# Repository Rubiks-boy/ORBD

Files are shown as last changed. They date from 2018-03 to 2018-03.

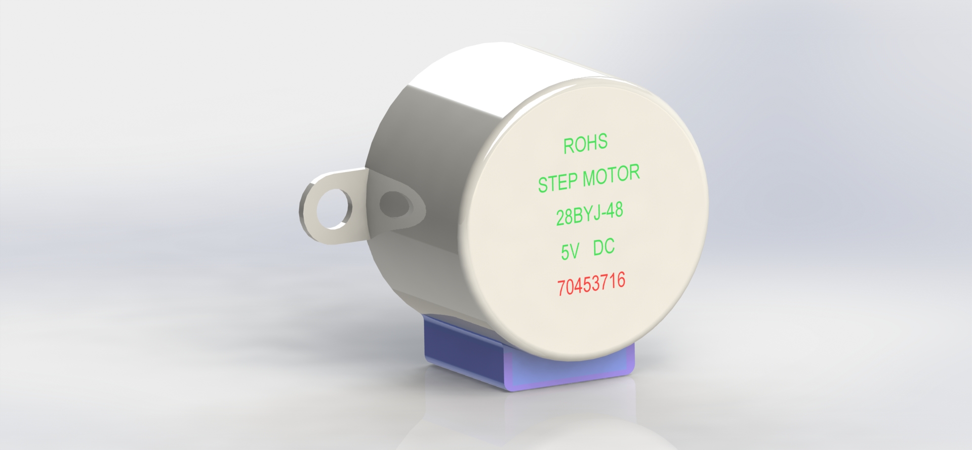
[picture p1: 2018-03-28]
IPT Inventor Files/Stepper Motor/5v DC step motor (back).JPG

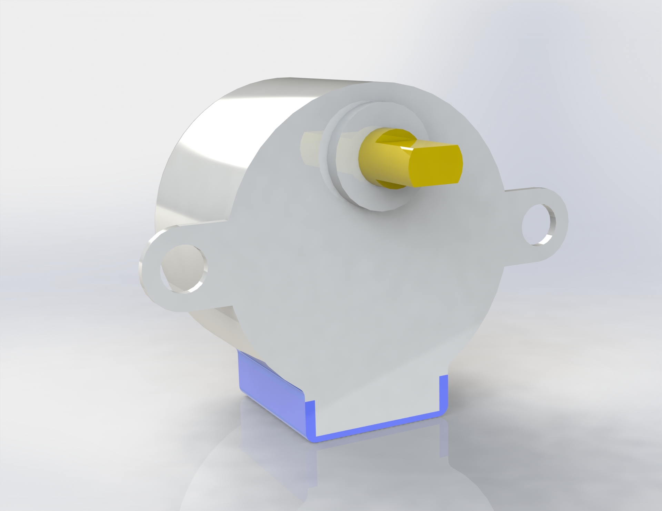
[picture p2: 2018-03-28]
IPT Inventor Files/Stepper Motor/5V Step motor.JPG

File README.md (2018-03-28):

# ORBD
Open Refreshable Braille Display - Science Fair Project by Adam Walker &amp; Russell Ro

This project uses motors in order to spin wheels that display a variety of braille characters quickly at less than 1% of the cost of present braille displays on the market.

Abstract:

285 million people are estimated to be visually impaired worldwide. Many of these individuals do not have access to blind-assistive technology primarily due to cost and accessibility. One such device, the refreshable braille display, converts digital text to a tactile readout providing a valuable tool in reading and writing applications. However, prices range from $3,500 to $15,000 making it difficult for many low-income visually impaired individuals to buy a device, especially since non-institutionalized persons aged 21-64 years with a visual disability have a median annual household income of $39,700 and about 29% of them live below the poverty line. Since many refreshable braille displays are prohibitively expensive, previous approaches have attempted to lower its cost by restricting the number of characters displayed, but this arose the new problem of higher translation error rates. In order to make refreshable braille displays more effective for a greater number of visually impaired individuals, our open-source device, ORBD, will provide a cheaper alternative to existing braille displays that does not sacrifice on readability, including the number of characters. ORBD is controlled by an Arduino microcontroller that takes digital input through a computer and translates those characters to a stepper motor position. An octagonal tactile surface connected to the motor via gear train displays the characters accordingly. Depending on user preference, more characters may be added by attaching extra gears and stepper motors. By accounting for accessibility through it being open-source, users have access to assembling their own refreshable braille display with parts that amount to a fraction of other devices’ prices.

This project competed at the Beal Bank USA Southern Nevada Regional Science & Engineering Fair at the University of Nevada, Las Vegas on March 14, 2018.

Adam Walker - adamwalker567123@gmail.com (Programming)
Russell Ro - pr.russell.ro@gmail.com (3D Modeling)

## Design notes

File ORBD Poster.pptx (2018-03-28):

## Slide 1

- Russell Ro, Adam Walker

- Advanced Technologies Academy, Las Vegas NV 89106

- Open Refreshable Braille Display (ORBD)

- Introduction

- 285 million people are estimated to be visually impaired worldwide.
- Non-institutionalized persons aged 21-64 years have median annual household income of $39,700 and about 29% of them live below the poverty line.
- A refreshable braille display converts digital text to a tactile readout providing a valuable tool in reading and writing applications.
- Prices range from $3,500 to $15,000.
- Cheaper alternatives suffered from higher translation error rates due to restricted number of characters.
- Open Refreshable Braille Display
- Arduino microcontroller-based that takes digital input through serial and translates those characters to braille readout.
- Accessibility: Budget set to approximately $100; will be released as an open-source device.
- Education: Practical in educational settings through use of digital text translation (i.e. textbooks, homework, etc.).
- Character Limitation: Doesn’t sacrifice on readability due to a character additive design.

- Hardware

- Results and Discussion

- The Open Refreshable Braille Display (ORBD) satisfies three objectives:
- Accessibility: Comprised of easily-obtainable hardware that amounts to approximately $70 if built personally or as low as $15 if mass-produced.
- Education: Successfully translates characters typed onto a computer to a stepper motor’s position which outputs braille characters; allows for an instructor to use as real-time educational tool (i.e. teaching braille characters).
- Character Limitation: Utilizes an axle and 3D-printed parts, allowing the user to expand the amount of characters on their device; each additional character costs about $3 (includes stepper motor, driver, and 3D-printed parts).

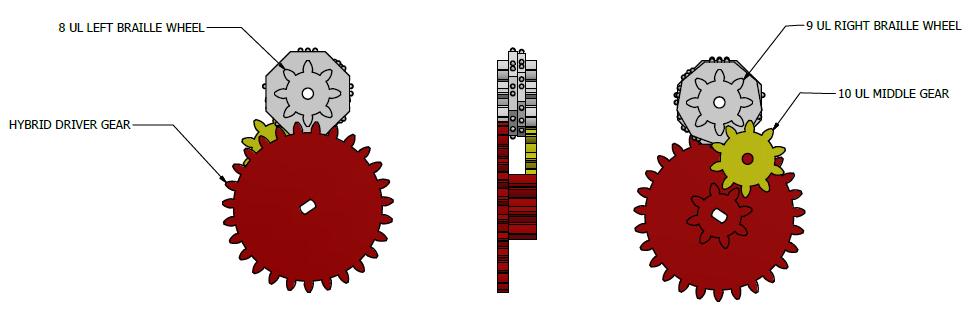
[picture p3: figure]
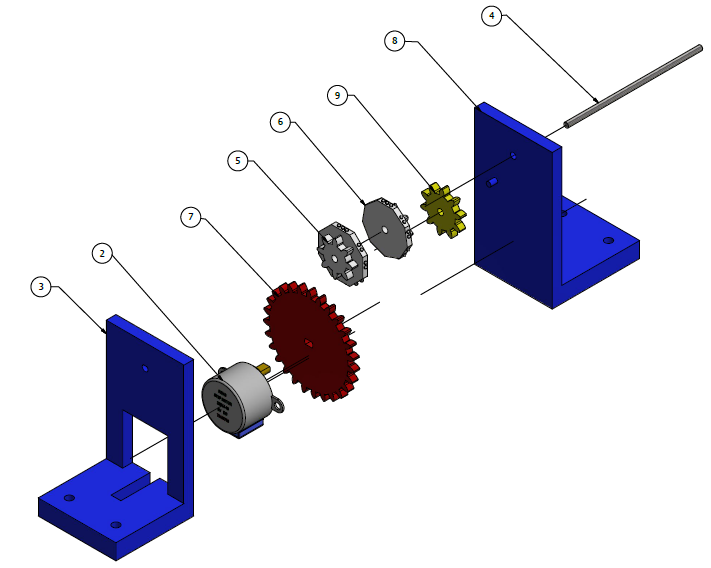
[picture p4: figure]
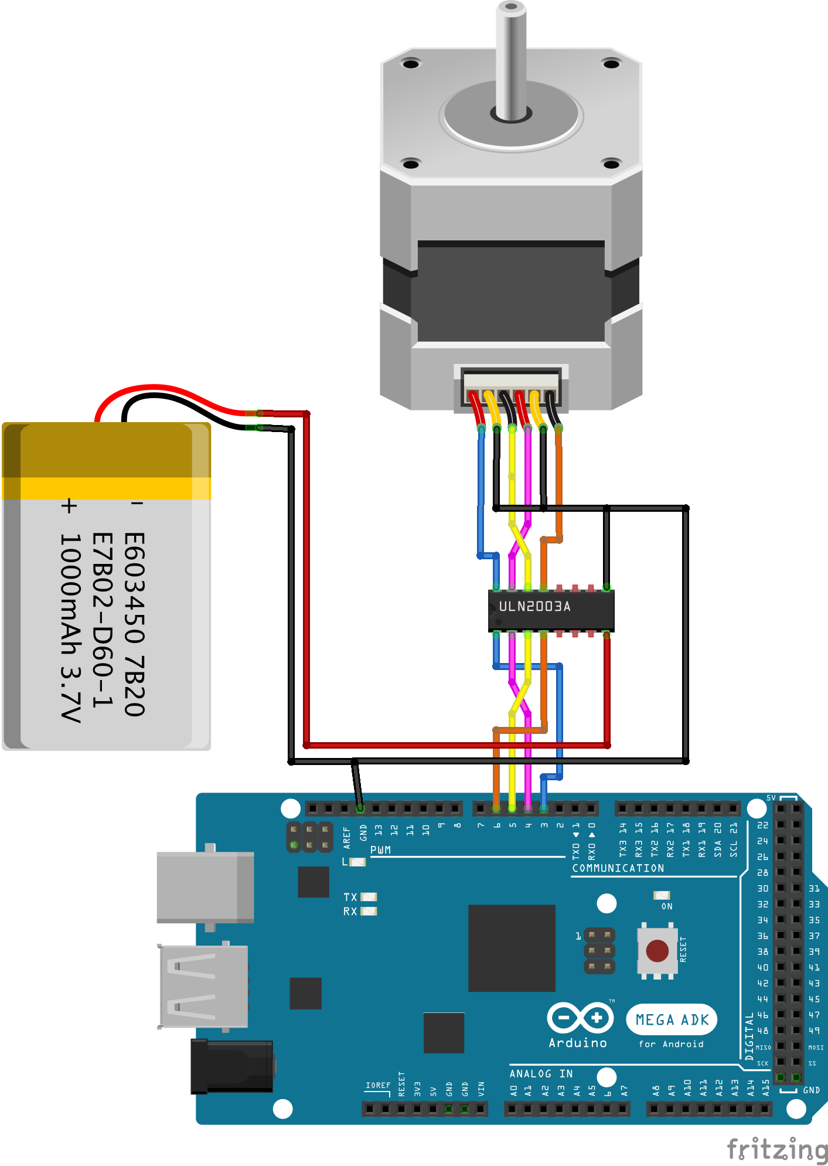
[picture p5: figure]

The ‘Hybrid Driver Gear’ consists of two sets of gear: one with 27 teeth and one with 8 teeth. The 27-tooth gear drives the 8-tooth octagonal left braille wheel, while the 8-tooth gear drives the 8-tooth nonagonal right braille wheel with a 10-tooth middle gear in between.

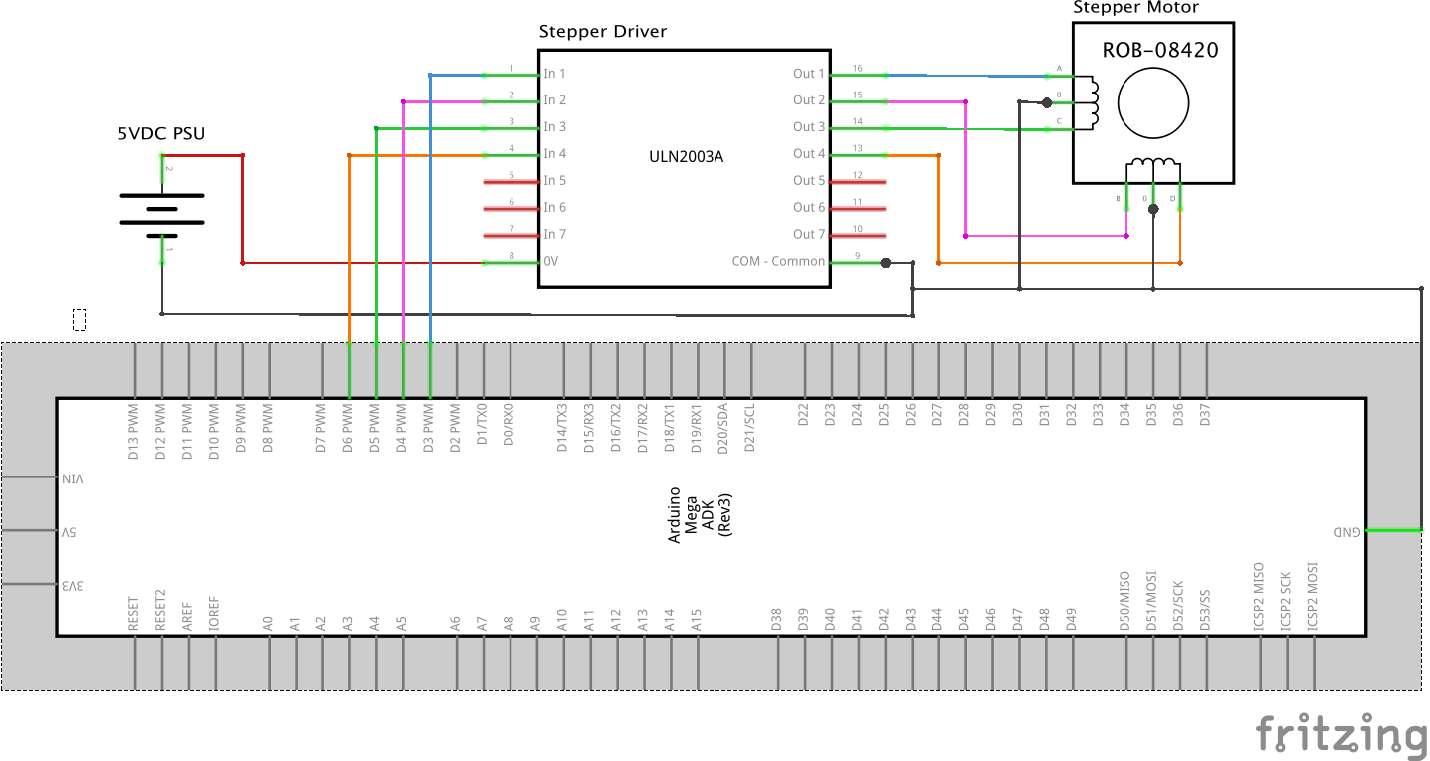
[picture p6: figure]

Gear Ratio Simulations

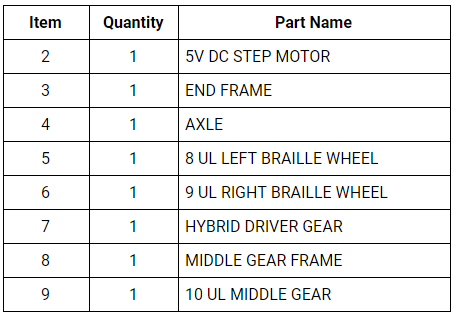
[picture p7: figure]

ORBD is a gear-based stepper motor concept that uses one stepper motor per character. Since this design saves on costs as it uses one motor for the two braille wheels that comprise one character instead of two motors. In order to find the ideal gear ratios, we ran simulations and resulted in using an 8:27 gear ratio that runs octagonal and nonagonal braille wheels per character. The 8:27 was chosen for its reasonable tooth-proportions and lowest average iterations to get from one character to the next (17.5). However, this design resulted in more challenges compared to the simpler, more expensive concepts:
- Extra gears made the device more prone to jams especially given that 3D printed parts aren’t perfect.
- It takes longer to translate digital text to braille output due to the device having less motors.
- Although ORBD has the additive character feature, each character is much bigger than current models’ character making for an inconveniently-sized braille display.
However, the benefits outweigh the drawbacks due to cost. The ORBD stands at an affordable $70 compared to the average price range of $3,500 to $15,000. With open-source access, ORBD has the potential to reach the millions of visually-impaired people who need it most.

Design Concepts

Solenoid-Based Concept: Each “bump” is raised using solenoids arranged in a 2x3 grid.
Pros:
- Characters change near instantaneously
Cons:
- Solenoids are too large & too many I/O pins to expand past a handful of characters.
- Power is required at all times to keep characters.

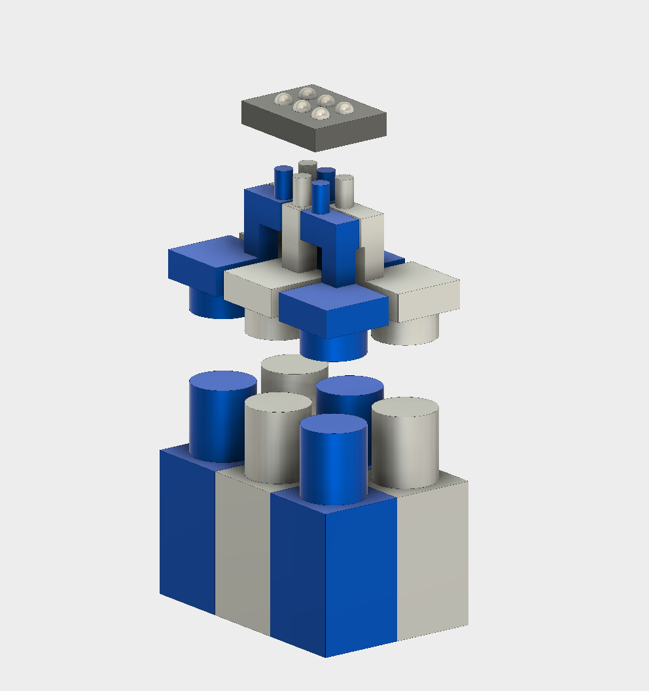
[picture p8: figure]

- To reduce costs and size, the left and right wheels are geared together. As it is necessary for the gears to maintain a flat surface at all times, the gear ratio must be such that all 64 combinations of characters* can be displayed accurately. A computer simulation was used to test the efficiency of various gear ratios.
- Let L and R be the number of positions on the left and right wheels, respectively.
- For every position moved forward on the right wheel, let n be the number of positions the left wheel moves such that 2 ≤ n < L.
- When there are eight positions on each wheel (L = R = 8), there is no n that will display all 64 combinations.
- Thus, we ran simulations that add “nothing” positions that don’t display characters:
- For every left wheel size L such that 8 ≤ L < 25
- For every right wheel size R such that 8 ≤ R < 25
- For every ratio n such that 2 ≤ n < L
- If every single position can be displayed, we log the mean and maximum number of iterations required (one iteration being moving one position forward on the slower wheel) to reach any character.
- The simulation ran forwards only. These numbers can be cut in half by running motors backwards and forwards.
- In addition, the true gear ratio that resulted was calculated and logged
- * Each wheel is responsible for one column of three bumps with 2³=8 permutations. Thus, there are 8²=64 possible characters that can be displayed.

Ave(Iter.) | Max(Iter.) | Slow Size R | Fast Size L | Pos Ratio n | Ave(R Revs) | Max(R Revs) | Ave(L Revs) | Max(L Revs) | Actual Gear Ratio
35 | 70 | 9 | 8 | 3 | 3.89 | 7.78 | 13.13 | 26.25 | 8:27
35 | 70 | 9 | 8 | 5 | 3.89 | 7.78 | 21.88 | 43.75 | 8:45
35 | 70 | 9 | 8 | 7 | 3.89 | 7.78 | 30.63 | 61.25 | 8:63
35 | 70 | 9 | 8 | 9 | 3.89 | 7.78 | 39.38 | 78.75 | 8:81
35 | 70 | 9 | 8 | 11 | 3.89 | 7.78 | 48.13 | 96.25 | 8:99
35 | 70 | 9 | 8 | 13 | 3.89 | 7.78 | 56.88 | 113.75 | 8:117
35 | 70 | 9 | 8 | 15 | 3.89 | 7.78 | 65.63 | 131.25 | 8:135
…
379 | 529 | 24 | 23 | 22 | 15.79 | 22.04 | 362.4 | 506 | 23:528

Travel Times

Based on the simulations, R = 9, L = 8, n = 3, and an 8:27 gear ratio was the most efficient (both in average time and in worst-case scenarios) and yielded the quickest travel times for a single character. As more characters are added, the travel iterations and travel times are logarithmic in shape and approach the values of 35 iterations and 15.575 seconds (@15RPM), respectively, as the number of characters approaches infinity.
In testing the responsiveness of changing characters, there is a negligible delay that averages 4ms, no matter the motor’s speed, as measured by the Arduino. Though the stepper motor’s top speed was approximately 20 RPM, all tests were conducted at 15 RPM to ensure the stepper motor did not lose steps.

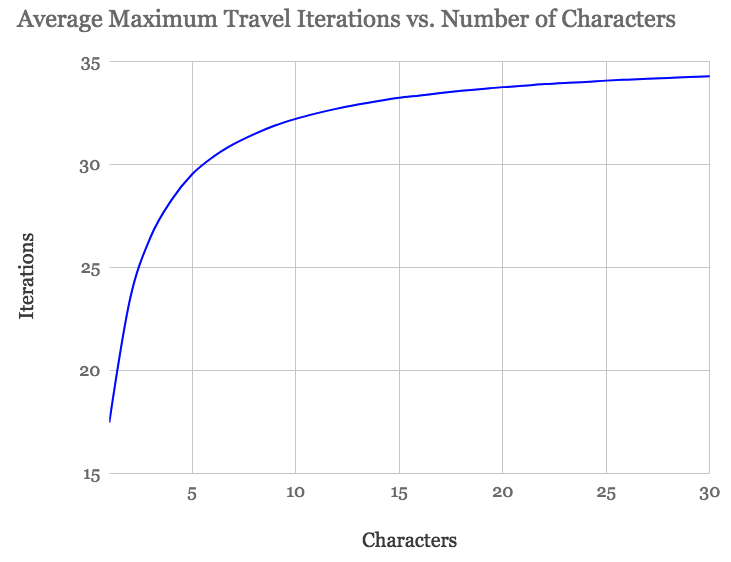
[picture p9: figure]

Derailleur Concept: Similar to a bicycle changing gears, a mechanism allows switching between characters displayed on a single wheel of 8 combinations of bumps.
Pros:
- Two motors required for a theoretically infinite number of characters.
Cons:
- One wheel can be moved at a time.
- The mechanism to switch wheels is complex, causing greater potential for jams.

Gear-Based Stepper Motor Concepts: Wheels of 8 combinations of bumps (1 column of a character) are driven by stepper motors.
V1: One stepper motor per wheel (2 per character)
V2: One stepper motor per character & a 27:8 gear ratio connects the two wheels.
Pros:
- Uses only one motor (V2) or two motors (V1) per wheel.
- In V1, each motor travels at most half of a revolution. In V2, on average, the faster wheel travels 6.56 revolutions and the slower 1.94.
- Allows characters to be placed next to each other as long as there are I/O pins.
- All motors can be driven at the same time.
Cons:
- Requires two stepper motors per character, resulting in greater cost and size. This may require more space between each character.
- Each motor requires a stepper motor driver, and the power supply must be strong enough to drive every motor.
- If the microcontroller loses power or the stepper loses steps, the device loses track of its position.

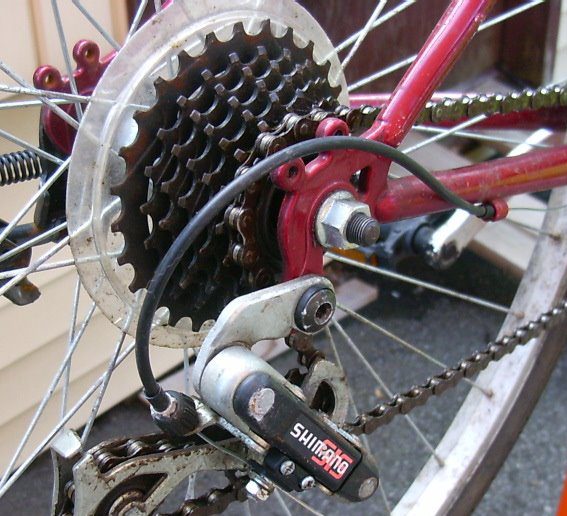
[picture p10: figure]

http://www.howtofixbikes.ca/2006/07/adjusting-your-derailleur.html

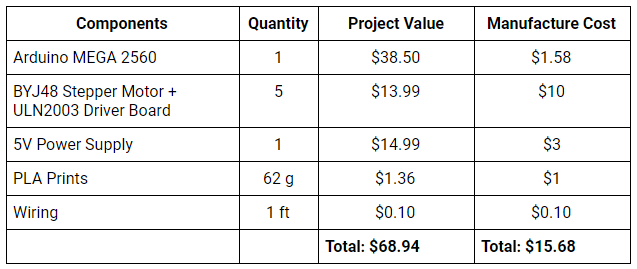
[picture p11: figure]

- Conclusion

- The Open Refreshable Braille Display is able to convert digital text into familiar braille text in a way that does not sacrifice readability. Its form factor is expandable, theoretically allowing for more characters than anything currently on the market. Most importantly, it could be manufactured for as little as one one-thousandth the cost of existing displays, removing any economic barrier. As an open-source alternative, ORBD will be able to revolutionize computer use, including for e-books and e-textbooks, for the visually impaired.

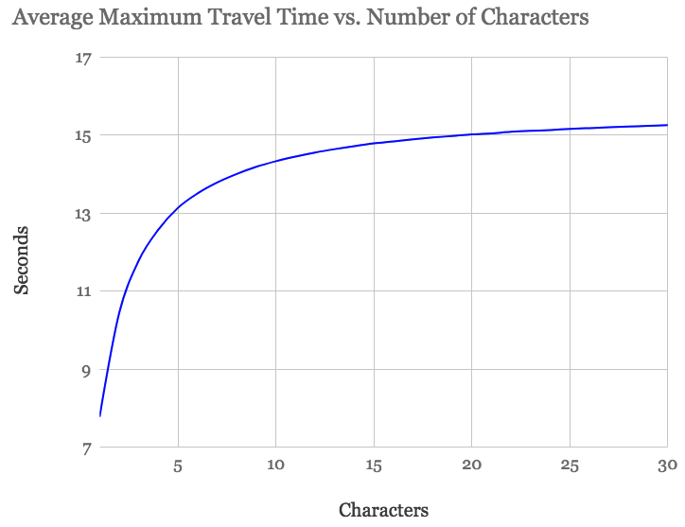
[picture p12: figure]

- References

- Vision impairment and blindness. (2017, October). Retrieved January 21, 2018, from http://www.who.int/mediacentre/factsheets/fs282/en/
- Refreshable Braille Displays. (n.d.). Retrieved January 21, 2018, from http://www.afb.org/prodBrowseCatResults.aspx?CatID=43
- Blindness Statistics. (n.d.). Retrieved January 21, 2018, from https://nfb.org/blindness-statistics
- Russomanno, A., Omodhrain, S., Gillespie, R. B., & Rodger, M. W. (2015). Refreshing Refreshable Braille Displays. IEEE Transactions on Haptics,8(3), 287-297. doi:10.1109/toh.2015.2423492

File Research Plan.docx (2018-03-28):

Open Refreshable Braille Display (ORBD)

Russell Ro, High School Student

Adam Walker, High School Student

Advanced Technologies Academy

1411 Robin Street

Las Vegas, NV 89106

Contact:

pr.russell.ro@gmail.com, 626-828-0560

adamwalker567123@gmail.com, 702-330-2590

Rationale

285 million people are estimated to be visually impaired worldwide [1]. Many of these individuals do not have access to blind-assistive technology primarily due to cost and accessibility. One such device, the refreshable braille display, converts digital text to a tactile readout providing a valuable tool in reading and writing applications. However, prices range from $3,500 to $15,000 [2] making it difficult for many low-income visually impaired individuals to buy a device, especially since non-institutionalized persons aged 21-64 years with a visual disability have a median annual household income of $39,700 and about 29% of them live below the poverty line [3]. Since many refreshable braille displays are prohibitively expensive, previous approaches have attempted to lower its cost by restricting the number of characters displayed, but this arose the new problem of higher translation error rates [4]. In order to make refreshable braille displays more effective for a greater number of visually impaired individuals, our open-source device, ORBD, will provide a cheaper alternative to existing braille displays that does not sacrifice on readability, including the number of characters.

Question

What changes to the refreshable braille display can allow for more affordability and accessibility?

Hypothesis

A new refreshable braille display design will be able to reach more visually impaired individuals without sacrificing its usability.

Engineering Goals

- Draft multiple design possibilities to pursue
- Prototype a new approach to a refreshable display at a feasible price
- Can display computer text input in a standard braille alphabet
- Minimizes cost
- Provides an expandable platform to increase the number of characters
- Make device open-source for public accessibility
- If time permits, receive feedback from the Blind Center of Nevada
- Test the readability of the device
- Donate the prototype to allow for further feedback and research

Expected Outcomes

A printer-based rail design allows for a stepper motor and gear to turn wheels with tactile braille to appropriate characters. Magnets will assist the wheels to stay at their appropriate characters. Since the wheels rest on a central axle and the motor on the rail theoretically has unlimited extendability, more wheels may be added allowing for more characters to be displayed.

Procedures

1. Pre-planning a prototype by making schematics, 3D models, and preliminary plans for development.
2. Assemble the prototype, including using soldering, 3D printers, and other techniques to develop an original design.
3. After each prototype revision, test the following measurements:
  a. Accuracy and readability of characters displayed
    i. Compare output to standard braille alphabet
    ii. Compare height of characters and spacing of characters to standards for height and spacing
    iii. If time permits, allow individuals to provide feedback on the readability of the display
  b. Attributes of the design
    i. Measure the speed of changing characters, including mean, variance, best case, and worst case
    ii. Calculate and log all costs, including electronics and 3D printed components
    iii. Measure size of device and power usage
    iv. Other attributes as applicable
  c. Attributes of the design
    i. Compare ORBD designs, drafts, and prototypes based on criteria in (a) and (b), as applicable
    ii. Compare these attributes with other displays currently on the market, as applicable

Risk and Safety

There will be no risks to any participants or other parts involved in data collection. During assembling, 3D printers and soldering pose a potential heat risk, but by following proper precautions, this risk will remain at a minimum. Low-voltage and low-amperage electronics pose minimal to no risk.

Data Analysis

The device must first prioritize power efficiency as inefficient actuator design may limit the performance of the microcontroller, so power capabilities will be considered in the draft designs. Next, the speed and accuracy will be measured through inputting characters on a computer, translating them to the display, and recording the time it took and the correctness of the characters based on what was inputted in the computer. Lastly, a cost-benefit analysis for the draft designs and prototype will detail its feasibility as compared to other models.

Bibliography

[1] Vision impairment and blindness. (2017, October). Retrieved January 21, 2018, from http://www.who.int/mediacentre/factsheets/fs282/en/
[2] Refreshable Braille Displays. (n.d.). Retrieved January 21, 2018, from http://www.afb.org/prodBrowseCatResults.aspx?CatID=43
[3] Blindness Statistics. (n.d.). Retrieved January 21, 2018, from https://nfb.org/blindness-statistics
[4] Russomanno, A., Omodhrain, S., Gillespie, R. B., & Rodger, M. W. (2015). Refreshing Refreshable Braille Displays. IEEE Transactions on Haptics,8(3), 287-297. doi:10.1109/toh.2015.2423492

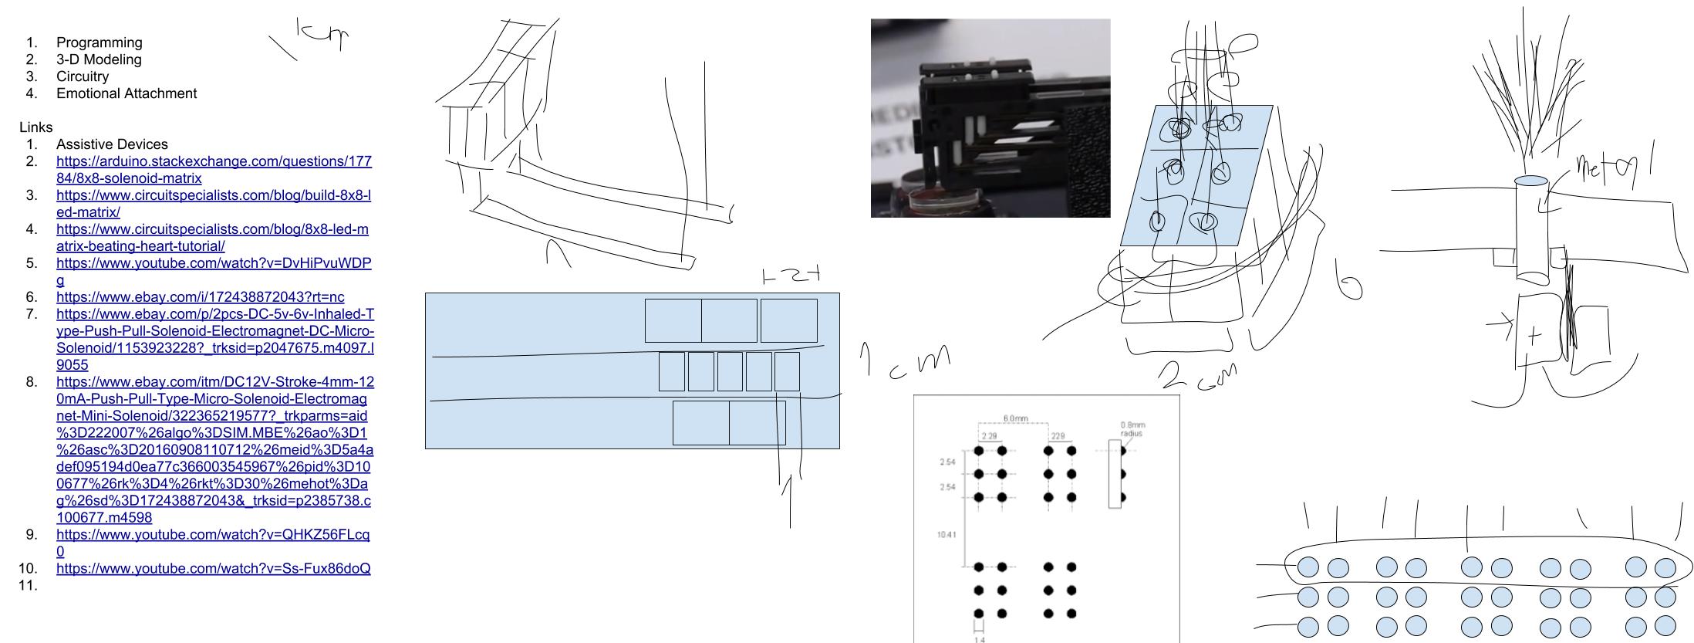
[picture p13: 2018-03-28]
Data and Visuals/Brainstorm Drawing.jpg

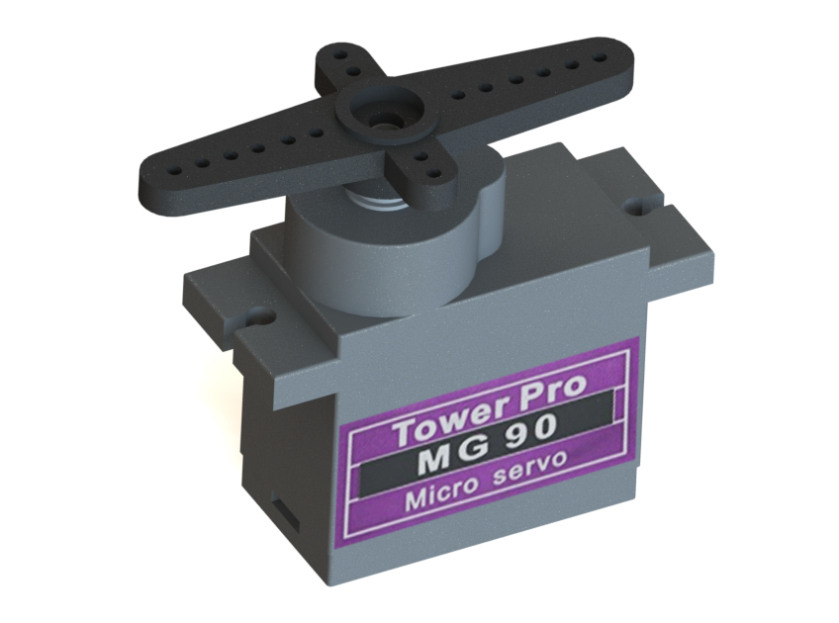
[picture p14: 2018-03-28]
IPT Inventor Files/Renderings/Render1.png

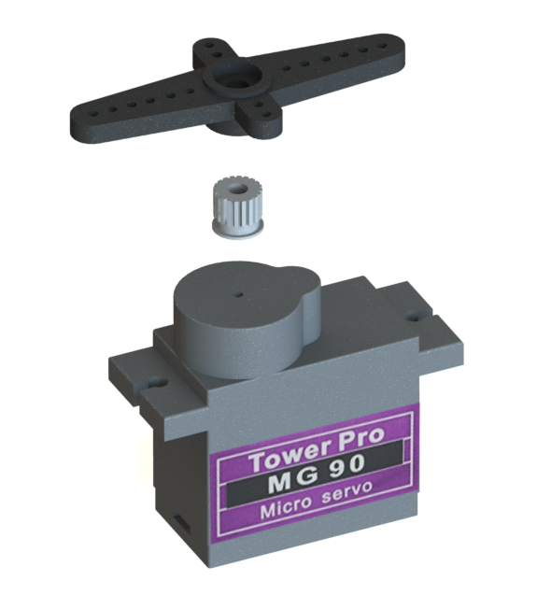
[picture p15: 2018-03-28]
IPT Inventor Files/Renderings/Render2.png

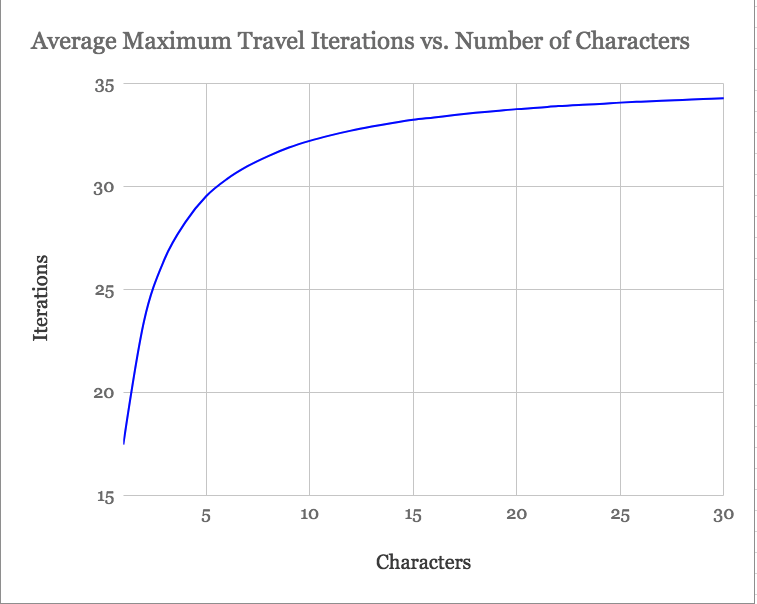
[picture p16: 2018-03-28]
Data and Visuals/travel iterations v num chars.png

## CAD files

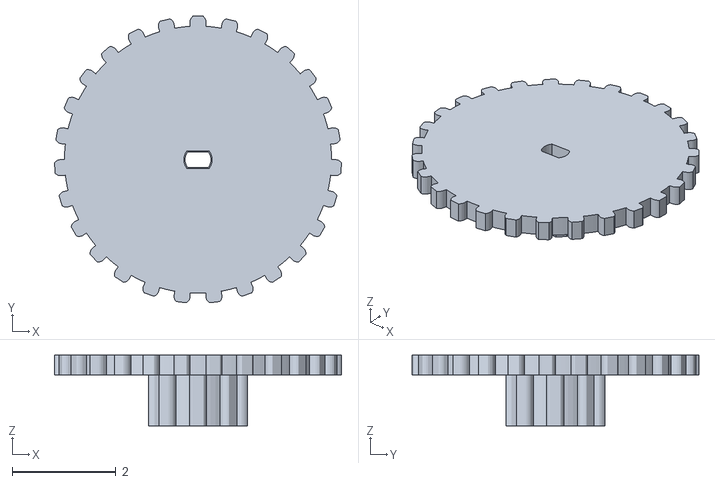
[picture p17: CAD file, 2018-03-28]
Final 3D Modeling STLs/Hybrid Driver Gear.stl
5.53 x 5.52 x 1.36

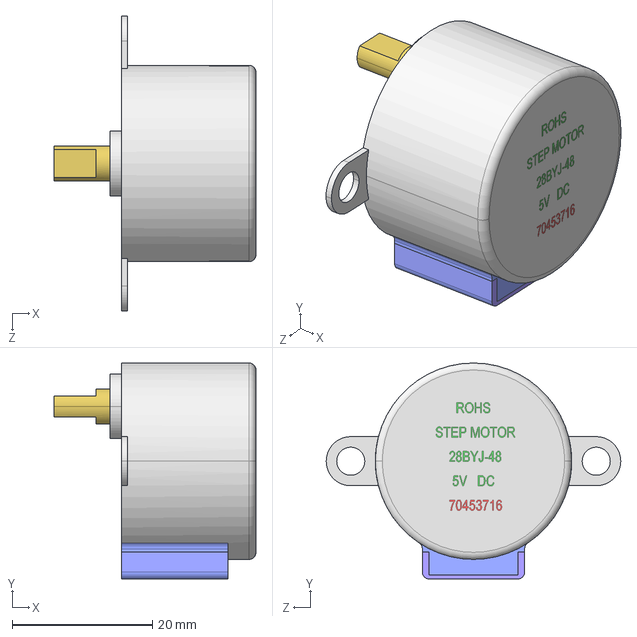
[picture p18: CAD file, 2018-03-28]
IPT Inventor Files/Stepper Motor/5V DC STEP MOTOR.STEP
28.8 x 30.8 x 42.0 mm

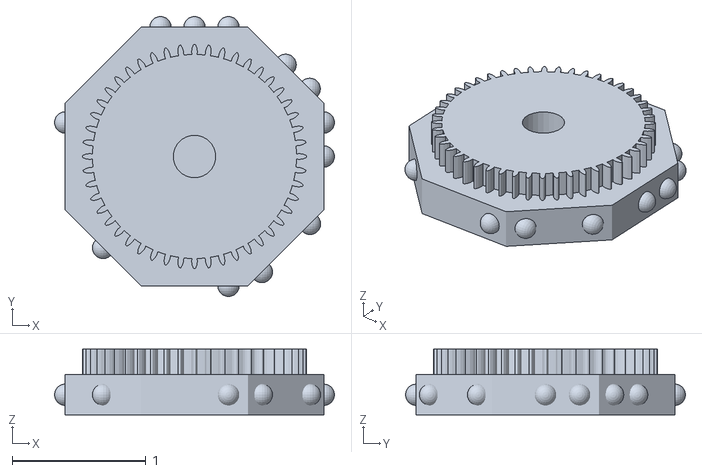
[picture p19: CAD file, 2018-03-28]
IPT Inventor Files/STLs Not In Use/Braille Wheel 1.stl
2.09 x 2.09 x 0.491

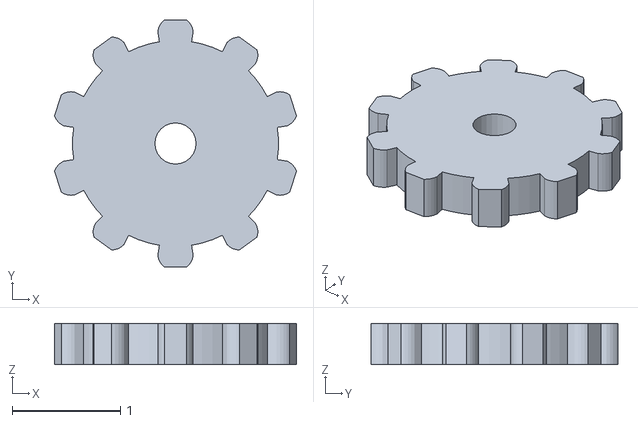
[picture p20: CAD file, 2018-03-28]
Final 3D Modeling STLs/10 ul Middle Gear.stl
2.24 x 2.29 x 0.381

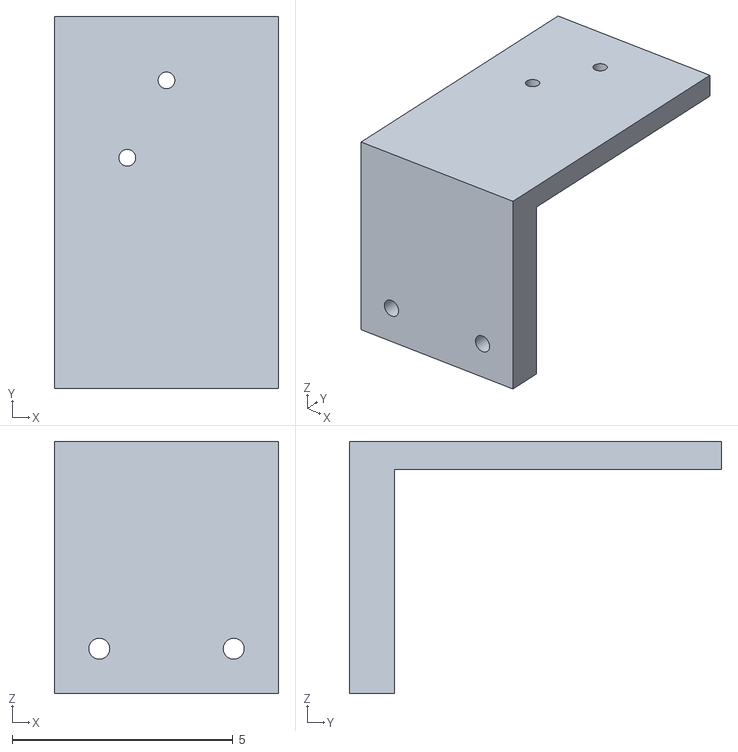
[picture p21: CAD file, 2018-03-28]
IPT Inventor Files/STLs Not In Use/Middle Gear Frame.stl
5.08 x 8.43 x 5.71

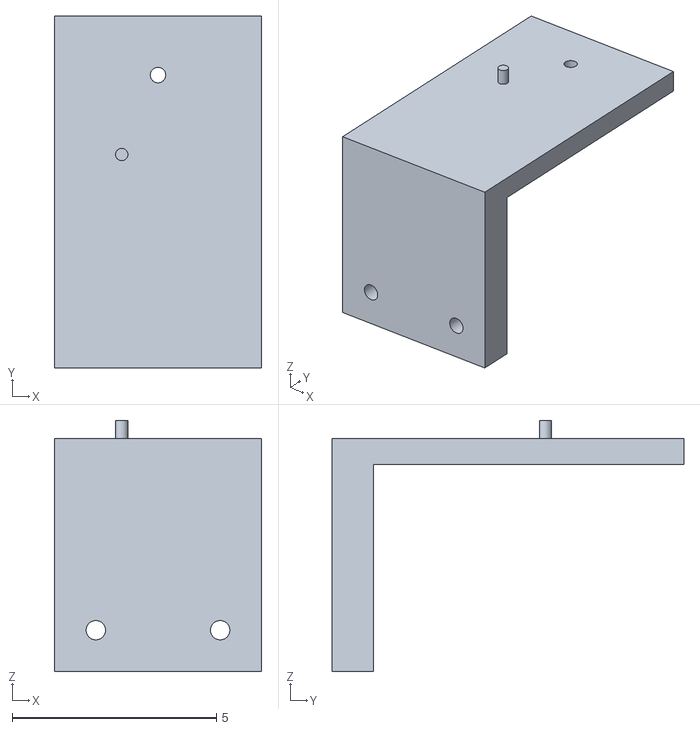
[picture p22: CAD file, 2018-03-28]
Final 3D Modeling STLs/Middle Gear Frame 2.stl
5.08 x 8.63 x 6.16

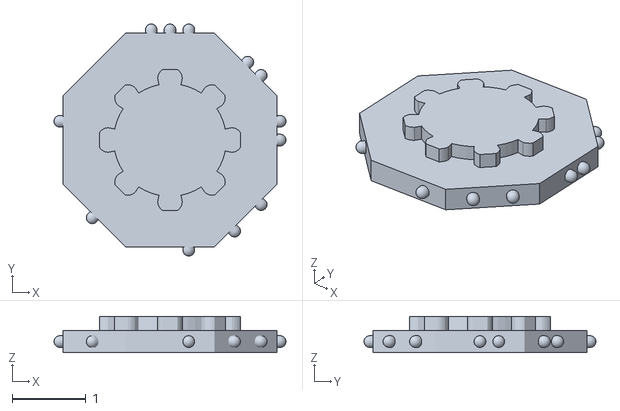
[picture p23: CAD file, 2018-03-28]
IPT Inventor Files/STLs Not In Use/Braille Wheel 3.stl
3.14 x 3.14 x 0.491

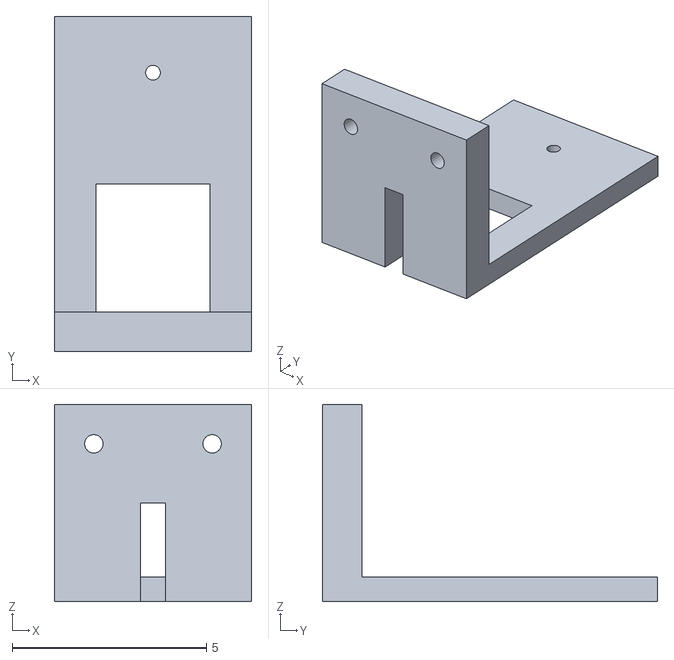
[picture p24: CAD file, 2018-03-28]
Final 3D Modeling STLs/Stepper Motor Frame 2.stl
5.08 x 8.63 x 5.08

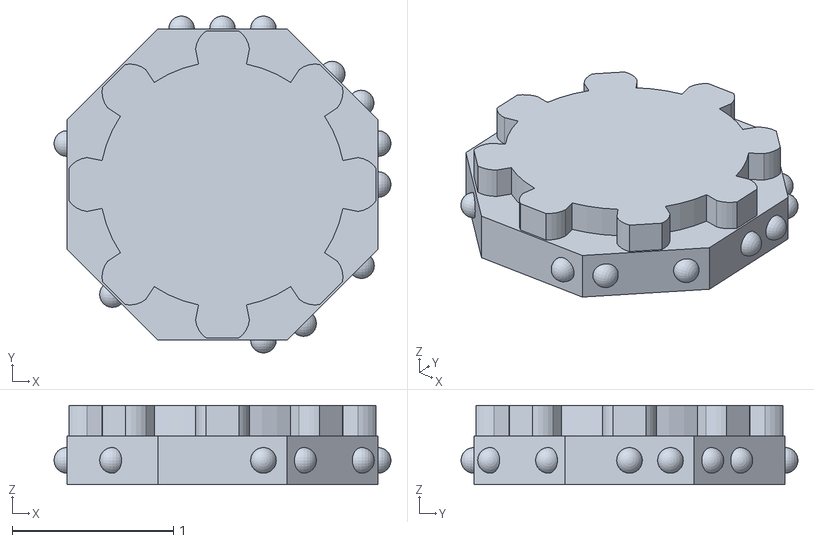
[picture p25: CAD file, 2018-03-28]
IPT Inventor Files/STLs Not In Use/Braille Wheel 2.stl
2.09 x 2.09 x 0.491

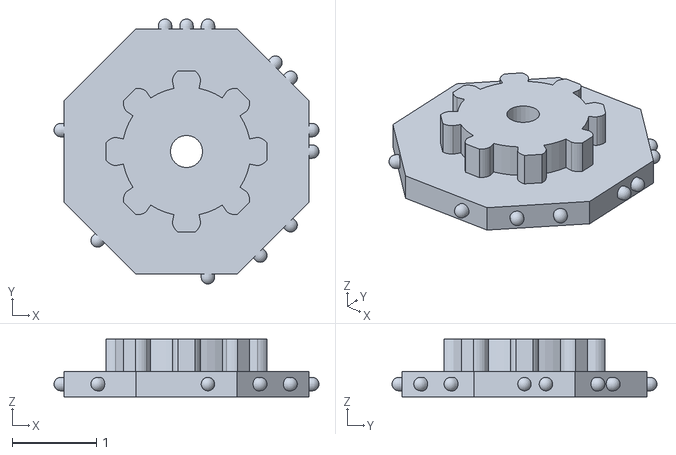
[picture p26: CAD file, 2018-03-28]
Final 3D Modeling STLs/8 ul Left Braille Wheel (Octagon).stl
3.14 x 3.14 x 0.681

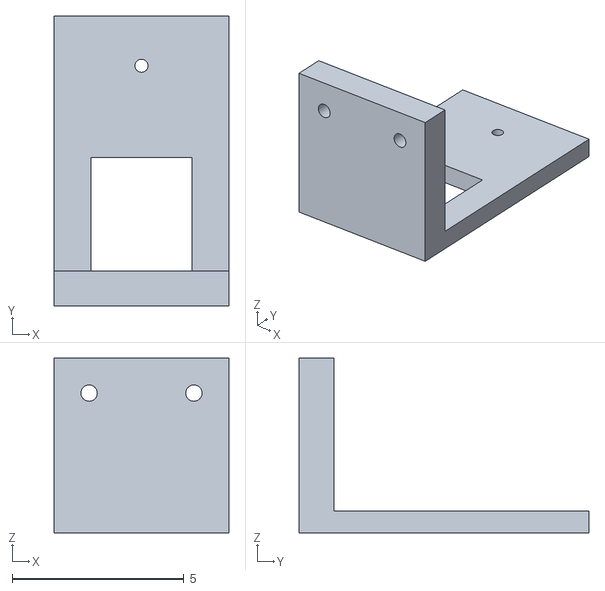
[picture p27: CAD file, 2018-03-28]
IPT Inventor Files/STLs Not In Use/Stepper Motor Frame.stl
5.08 x 8.43 x 5.08

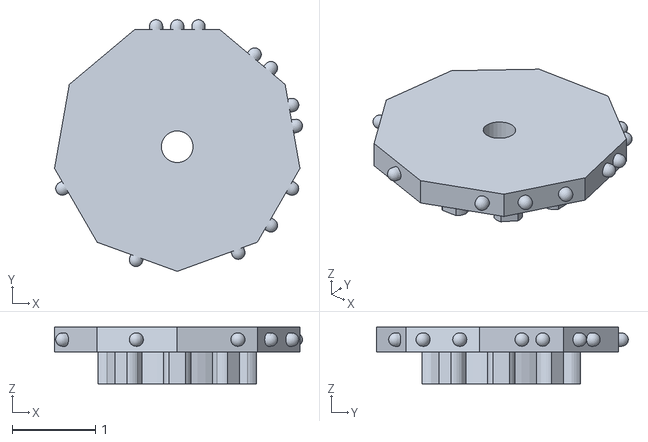
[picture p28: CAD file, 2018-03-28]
Final 3D Modeling STLs/8 ul Right Braille Wheel (Nonagon).stl
2.97 x 3.02 x 0.681

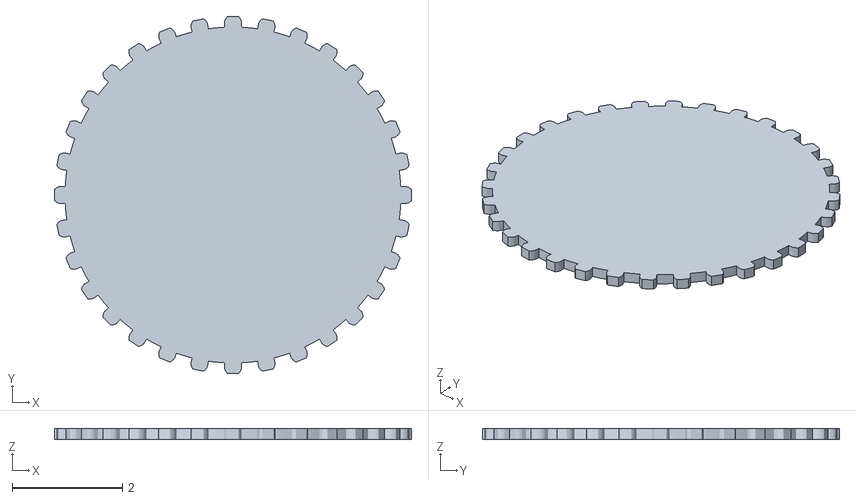
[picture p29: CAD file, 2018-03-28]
IPT Inventor Files/STLs Not In Use/Middle Gear 2.stl
6.48 x 6.48 x 0.191

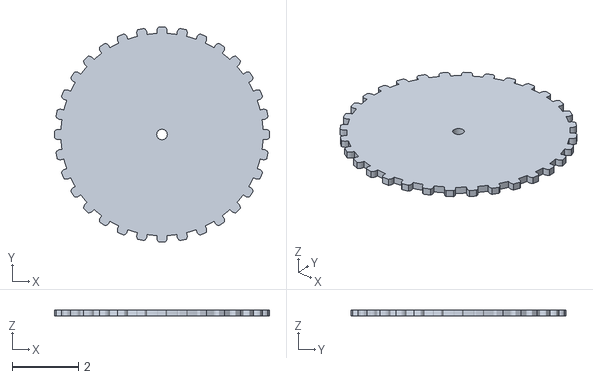
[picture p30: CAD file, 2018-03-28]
IPT Inventor Files/STLs Not In Use/Middle Gear.stl
6.48 x 6.48 x 0.191

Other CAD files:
IPT Inventor Files/10 ul Middle Gear.ipt
IPT Inventor Files/8 ul Left Braille Wheel (Octagon).ipt
IPT Inventor Files/8 ul Right Braille Wheel (Nonagon).ipt
IPT Inventor Files/Axle.ipt
IPT Inventor Files/Base.ipt
IPT Inventor Files/Hybrid Driver Gear.ipt
IPT Inventor Files/IPTs Not In Use/27 ul Driver Gear.ipt
IPT Inventor Files/IPTs Not In Use/32 ul Middle Gear.ipt
IPT Inventor Files/IPTs Not In Use/8 ul Driver Gear.ipt
IPT Inventor Files/IPTs Not In Use/8 ul Gear Holder.ipt
IPT Inventor Files/IPTs Not In Use/End Frame.ipt
IPT Inventor Files/IPTs Not In Use/Middle Frame.ipt
IPT Inventor Files/IPTs Not In Use/ORBD Assembly.iam
IPT Inventor Files/IPTs Not In Use/Right Braille Wheel.ipt
IPT Inventor Files/Middle Gear Frame.ipt
IPT Inventor Files/OldVersions/27 ul Driver Gear.0003.ipt
IPT Inventor Files/OldVersions/27 ul Driver Gear.0004.ipt
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

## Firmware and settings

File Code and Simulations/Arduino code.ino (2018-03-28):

#include <Stepper.h>

//Number of steps in each revolution
const int STEPS_PER_REV = 2048;

//number of characters (steppers) and the number of I/O pins each uses
const int NUM_CHARS = 2;
const int NUM_PINS = 4;

//speed of each stepper (RPM)
const int SPEED = 15;

//number of characters on the left and right character wheels
const int LEFT_POSITIONS = 8, RIGHT_POSITIONS = 9;

//increment value for each wheel
const int LEFT_INC = 3, RIGHT_INC = -1;

//pins each stepper uses
const int STEPPER_PINS[NUM_CHARS][NUM_PINS] = {{46, 50, 48, 52}, {3, 5, 4, 6}};
//button pin to display a new set of characters
const int NEXT_BTN_PIN = 7;

//every character it can display, along with corresponding wheel indexes
const int NUM_DISPLAYED_CHARS = 42;
const char ALPHABET [NUM_DISPLAYED_CHARS] = {'~', 'A', 'B', 'C', 'D', 'E', 'F', 'G', 'H', 'I', 'J', 'K', 'L', 'M', 'N', 'O', 'P', 'Q', 'R', 'S', 'T', 'U', 'V', 'W', 'X', 'Y', 'Z', '1', '2', '3', '4', '5', '6', '7', '8', '9', '0', '.', ',', '?', '!', '#'};
const int POS_LEFT [NUM_DISPLAYED_CHARS] = {0, 3, 5, 3, 3, 3, 5, 5, 5, 2, 2, 4, 7, 4, 4, 4, 7, 7, 7, 6, 6, 4, 7, 2, 4, 4, 4, 3, 5, 3, 3, 3, 5, 5, 5, 2, 2, 2, 2, 6, 6, 1};
const int POS_RIGHT [NUM_DISPLAYED_CHARS] = {0, 0, 0, 3, 5, 2, 3, 5, 2, 3, 5, 0, 0, 3, 5, 2, 3, 5, 2, 3, 5, 1, 1, 7, 4, 7, 6, 0, 0, 3, 5, 2, 3, 5, 2, 3, 5, 6, 0, 1, 2, 7};

//delay for debouncing
const unsigned long BTN_DEBOUNCE = 50;

//remainder number of steps due to integer division
int remainder[NUM_CHARS] = {0};

//whether its ready to display a new set of characters
boolean readyForNext = true;

///last button state
boolean lastBtn = 0;

//last time the button toggled
unsigned long lastBtnToggle = 0;

//characters to display in braille
String charBuffer = "";

//whether the readyForNext already toggled this press
boolean alreadyToggled = false;

//declare the list of stepper motors
Stepper steppers[NUM_CHARS] = 
{
  Stepper(STEPS_PER_REV, STEPPER_PINS[0][0], STEPPER_PINS[0][1], STEPPER_PINS[0][2], STEPPER_PINS[0][3]),
  Stepper(STEPS_PER_REV, STEPPER_PINS[1][0], STEPPER_PINS[1][1], STEPPER_PINS[1][2], STEPPER_PINS[1][3])
};

//current stepper locations
int leftWheelPos[NUM_CHARS];
int rightWheelPos[NUM_CHARS];

//how many iterations are required to achieve the desired position, moving forwards
int itersReqdForward(int motorIndex, int charIndex)
{
  int newL = leftWheelPos[motorIndex];
  int newR = rightWheelPos[motorIndex];
  int iters = 0;

  while(newL != POS_LEFT[charIndex] || (newR != POS_RIGHT[charIndex] && newR - 8 != POS_RIGHT[charIndex] && newR + 8 != POS_RIGHT[charIndex]))
  {
    iters++;
    
    //increment the wheel positions
    newL += LEFT_INC;
    newR += RIGHT_INC;

    //take care of index overflows/underflows
    while(newL >= LEFT_POSITIONS)
    {
      newL -= LEFT_POSITIONS;
    }
      
    while(newR < 0)
    {
      newR += RIGHT_POSITIONS;
    }
  }

  Serial.print("Steps Required Forward: ");
  Serial.println(iters);

  return iters;
}

//how many iterations are required to achieve the desired position, moving backwards
int itersReqdBackward(int motorIndex, int charIndex)
{
  //current stepper locations
  int newL = leftWheelPos[motorIndex];
  int newR = rightWheelPos[motorIndex];
  int iters = 0;

  while(newL != POS_LEFT[charIndex] || (newR != POS_RIGHT[charIndex] && newR - 8 != POS_RIGHT[charIndex] && newR + 8 != POS_RIGHT[charIndex]))
  {
    iters++;
    
    //increment the wheel positions
    newL -= LEFT_INC;
    newR -= RIGHT_INC;

    //take care of index overflows/underflows
    while(newL < 0)
    {
      newL += LEFT_POSITIONS;
    }
      
    while(newR >= RIGHT_POSITIONS)
    {
      newR -= RIGHT_POSITIONS;
    }
  }

  Serial.print("Steps Required Backward: ");
  Serial.println(iters);
  return iters;
}

//move stepper motorIndex forward one iteration
void moveStepperForward(int motorIndex)
{ 
  //increment the wheel positions
  leftWheelPos[motorIndex] += LEFT_INC;
  rightWheelPos[motorIndex] += RIGHT_INC;

  //take care of index overflows/underflows
  while(leftWheelPos[motorIndex] >= LEFT_POSITIONS)
  {
    leftWheelPos[motorIndex] -= LEFT_POSITIONS;
  }
    
  while(rightWheelPos[motorIndex] < 0)
  {
    rightWheelPos[motorIndex] += RIGHT_POSITIONS;
  }

  //move the stepper motor the necessary amount
  //and move a remainder of steps (occurs over time due to integer division)
  double dblSteps = 1.0 * STEPS_PER_REV * RIGHT_INC / RIGHT_POSITIONS;
  int numSteps = (int)dblSteps;
  remainder[motorIndex] += dblSteps - numSteps;
  if(remainder[motorIndex] > 1.0)
  {
    steppers[motorIndex].step((int)remainder);
    remainder[motorIndex] -= (int)(remainder);
  }
  steppers[motorIndex].step(numSteps);

  Serial.print("C:");
  Serial.print(motorIndex);
  Serial.print(": L:");
  Serial.print(leftWheelPos[motorIndex]);
  Serial.print(" R:");
  Serial.println(rightWheelPos[motorIndex]);
}

//move stepper motorIndex backward one iteration
void moveStepperBackward(int motorIndex)
{
  //increment the wheel positions
  leftWheelPos[motorIndex] -= LEFT_INC;
  rightWheelPos[motorIndex] -= RIGHT_INC;

  //take care of index overflows/underflows
  while(leftWheelPos[motorIndex] < 0)
  {
    leftWheelPos[motorIndex] += LEFT_POSITIONS;
  }
    
  while(rightWheelPos[motorIndex] >= RIGHT_POSITIONS)
  {
    rightWheelPos[motorIndex] -= RIGHT_POSITIONS;
  }

  //move the stepper motor the necessary amount
  //and move a remainder of steps (occurs over time due to integer division)
  double dblSteps = 1.0 * STEPS_PER_REV * RIGHT_INC / RIGHT_POSITIONS;
  int numSteps = (int)dblSteps;
  remainder[motorIndex] -= dblSteps - numSteps;
  if(remainder[motorIndex] < -1.0)
  {
    steppers[motorIndex].step((int)remainder);
    remainder[motorIndex] -= (int)(remainder);
  }
  steppers[motorIndex].step(-numSteps);

  Serial.print("Character ");
  Serial.print(motorIndex);
  Serial.print(": L:");
  Serial.print(leftWheelPos[motorIndex]);
  Serial.print(" R:");
  Serial.println(rightWheelPos[motorIndex]);
}

//moves the stepper motor motorIndex steps steps
void advanceSteps(int motorIndex, int steps)
{
  Serial.print("Advancing Character ");
  Serial.print(motorIndex);
  Serial.print(" ");
  Serial.print(steps);
  Serial.println(" steps.");
  steppers[motorIndex].step(steps);
}

//sets the position that a stepper is currently at
void setPosition(int motorIndex, int l, int r)
{
  leftWheelPos[motorIndex] = l;
  rightWheelPos[motorIndex] = r;
  Serial.print("\nC:");
  Serial.print(motorIndex);
  Serial.print(" L:");
  Serial.print(l);
  Serial.print(" R:");
  Serial.print(r);
}

void setup() 
{
  //open serial port
  Serial.begin(9600);

  //set the speed of each stepper (rpm)
  for(int i = 0; i < NUM_CHARS; i++)
  {
    steppers[i].setSpeed(SPEED);
    leftWheelPos[i] = rightWheelPos[i] = 0;
  }

  pinMode(NEXT_BTN_PIN, INPUT);
  pinMode(13, OUTPUT);
}

void loop() 
{
  //read the button & set up next character if wanted
  boolean currBtn = digitalRead(NEXT_BTN_PIN);
  
  if(currBtn != lastBtn)
  {
    lastBtnToggle = millis();
    alreadyToggled = false;
  }

  if(millis() - lastBtnToggle > BTN_DEBOUNCE && !alreadyToggled)
  {
    Serial.println("Ready to display next");
    digitalWrite(13, HIGH);
    readyForNext = true;
    alreadyToggled = true;
  }

  if(millis() - lastBtnToggle > BTN_DEBOUNCE + 250)
  {
    digitalWrite(13, LOW);
  }

  //check if anything is available to read
  if(Serial.available() > 0)
  {
    //read the character inputted
    char inChar = Serial.read();

    //advance n motor x steps
    if(inChar == '`')
    {
      int mIndex = Serial.parseInt();
      int numSteps = Serial.parseInt();
      advanceSteps(mIndex, numSteps);
    }

    //set n motor's current position (wheel indexes)
    else if(inChar == '@')
    {
      int mIndex = Serial.parseInt();
      int lPos = Serial.parseInt();
      int rPos = Serial.parseInt();
      setPosition(mIndex, lPos, rPos);
    }

    //zero all the characters
    else if(inChar == '~')
    {
      //for each motor index
      for(int m = 0; m < NUM_CHARS; m++)
      {
        //set the position to 0 for both left and right wheels
        
        Serial.print("\nZeroing Character ");
        Serial.println(m);

        //see if front or back is more efficient
        int fIters = itersReqdForward(m, 0);
        int bIters = itersReqdBackward(m, 0);

        //move the motors
        if(fIters == 0 && bIters == 0) {}
        else if(fIters <= bIters)
          for(int i = 0; i < fIters; i++)
          {
            Serial.print("Iter:");
            Serial.print(i);
            Serial.print(" ");
   
            moveStepperForward(m);
          }
        else 
          for(int i = 0; i < bIters; i++)
          {
            Serial.print("Iter:");
            Serial.print(i);
            Serial.print(" ");
   
            moveStepperBackward(m);
          }

        //remove current from stepper
        for(int i = 0; i < NUM_PINS; i++)
          digitalWrite(STEPPER_PINS[m][i], LOW);

        charBuffer = "";
      }
    }

    //manually move forward or back a number of iterations
    else if(inChar == '+')
    {
      int mIndex = Serial.parseInt();
      int numIters = Serial.parseInt();

      for(int i = 0; i < numIters; i++)
        moveStepperForward(mIndex);

      for(int i = 0; i < NUM_PINS; i++)
          digitalWrite(STEPPER_PINS[mIndex][i], LOW);
    }
    else if(inChar == '-')
    {
      int mIndex = Serial.parseInt();
      int numIters = Serial.parseInt();

      for(int i = 0; i < numIters; i++)
         moveStepperBackward(mIndex);

      for(int i = 0; i < NUM_PINS; i++)
          digitalWrite(STEPPER_PINS[mIndex][i], LOW);
    }

    //add character to the buffer to be displayed
    else
    {
      Serial.print("\nAdded to buffer: ");
      Serial.print(inChar);
      Serial.println();

      charBuffer += inChar;

      while(Serial.available() > 0)
      {
        inChar = Serial.read();
        Serial.print("\nAdded to buffer: ");
        Serial.print(inChar);
        Serial.println();
  
        charBuffer += inChar;
      }
    }
  }

  //ready to display the next character(s)
  if(readyForNext)
  {
    boolean ran = false;
    //run until we run out of motors or run out of characters to print
    for(int motorIndex = 0; motorIndex < NUM_CHARS && charBuffer != ""; motorIndex++)
    {
      ran = true;
      
      //find the current character
      char curr = charBuffer.charAt(0);
    
      Serial.print("\nDisplaying: ");
      Serial.print(curr);
      Serial.println();
  
      //find the character's index
      int i = 0;
      for(; i < NUM_DISPLAYED_CHARS; i++)
      {
        if(curr == ALPHABET[i])
          break;
      }
  
      //see if the character can't be displayed
      if(i == NUM_DISPLAYED_CHARS)
      {
        Serial.println("Invalid Character");
      }
      else
      {
        //see if going forwards or backwards is more efficient
        int fIters = itersReqdForward(motorIndex, i);
        int bIters = itersReqdBackward(motorIndex, i);
        Serial.print(fIters);
        Serial.print(" ");
        Serial.println(bIters);

        //move the more efficient route
        if(fIters == 0 && bIters == 0) {}
        else if(fIters <= bIters)
        {
          Serial.println("Moving Forward");
          for(int i = 0; i < fIters; i++)
          {
            Serial.print("Iter:");
            Serial.print(i);
            Serial.print(" ");
            moveStepperForward(motorIndex);
          }
        }
        else 
        {
          Serial.println("Moving Backwards");
          for(int i = 0; i < bIters; i++)
          {
            Serial.print("Iter:");
            Serial.print(i);
            Serial.print(" ");
            moveStepperBackward(motorIndex);
          }
        }

        //remove current from motor
        for(int i = 0; i < NUM_PINS; i++)
          digitalWrite(STEPPER_PINS[motorIndex][i], LOW);

        //remove first character from buffer
        charBuffer = charBuffer.substring(1);
      }
    }

    //completed this loop, wait until user presses button for the next
    if(ran)
      readyForNext = false;
  }

  //delay between iterations of the loop() function
  delay(10);
}
